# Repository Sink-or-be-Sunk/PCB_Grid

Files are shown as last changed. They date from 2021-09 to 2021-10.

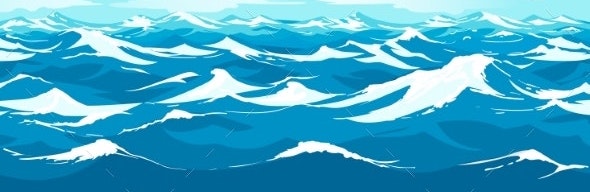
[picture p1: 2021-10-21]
assets/preview.jpeg

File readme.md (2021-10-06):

# Sink or be Sunk Grid PCB (Subcomponent)

This project contains the KiCAD PCB for one row of the attack of ship position boards
## Helpful Notes

### Nested Sheets

In KiCAD you can use a neat feature to split your project into multiple files. This not only helps to reduce cluter on one single diagram, it also allows for reuse of a common schematic element.

For this project specifically, the Grid.sch file can be reused for both the top (attack) grid and the bottom (ship positioning) grid.

`Hierarchical Labels` - KiCAD allows you to place a label on a nested sheet that can be viewed by the parenet sheet. Ex: you place a label on the STM32 Sheet and you can connect to it from the Main Layout schematic.

- Locate the `Hierarchical Labels` button on the right hand toolbar in kicad to place a label in a child sheet.
  - See section A4 of the STM32 Sheet
- Navigate back to the parent sheet and right click on the child sheet where you jused added the label
- Select the `import sheet pins` option
  - NOTE that you will have to do this for every new pin that you add to the child sheet, kinda repetative if you have a bunch of heirarchical labels...

`ESP32 Reference Design` - Adafruit produced a reference/dev board for the ESP32. They have great documentation on the device and are generous enough to include images of their schematic. This is a good place to start for our design. See the [Adafruit Website](https://learn.adafruit.com/adafruit-huzzah32-esp32-feather/downloads) for details.

#### Gride/Row PCB Updates

Started making some progress on our PCB layout. I'm already a little worried about space constraints. For a little more reference on the sizing: the width of the board is 22cm (2.5cm of extra clearance + 8in(20.32cm) = 22.82cm, rounded to 22cm to be on the safe side) and the length/height of the board is 2cm (0.787in). I was thinking to align one edge of each PCB with the edge of the grid - moreover, keep the 2.5cm extra all to one side for the resistor array, mux, connectors, etc.

The resistor array is pretty large, and I think we may have some issues trying to fit it on the board without running into a grid square. The same goes for the mux and the connectors we have chosen. On the brightside, if we make the board 2cm tall then that gives roughly 0.5cm of spacing between the boards. That's a good chunk of room. I'm trying to account for the wire connections, but could we thread the wires underneath the board? It will be on standoffs anyway.

Some things to consider:
- Is the resistor array worth it? Individual resistors = more solder time, resistor array = space constraints 
- Realistically, do we need a gap between rows? If so, how much? 

Looking forward, I think this PCB will be much simpler to layout, but will take a LOT of focus and attention to detail. The spacing is the most important part of this board. We will need to double, triple check this before purchasing.

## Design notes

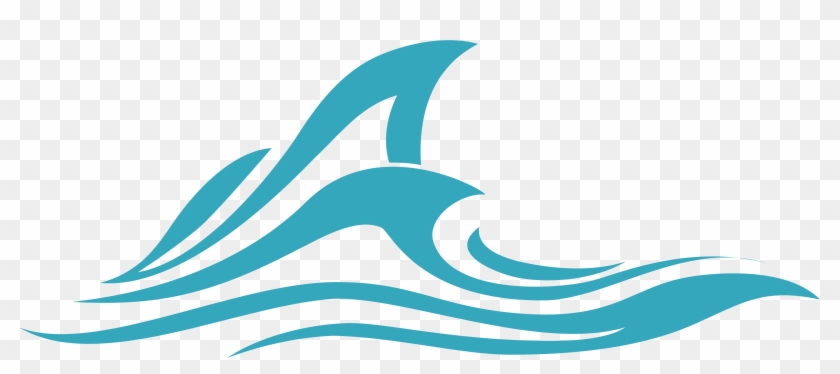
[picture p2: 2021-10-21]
assets/one_wave.png

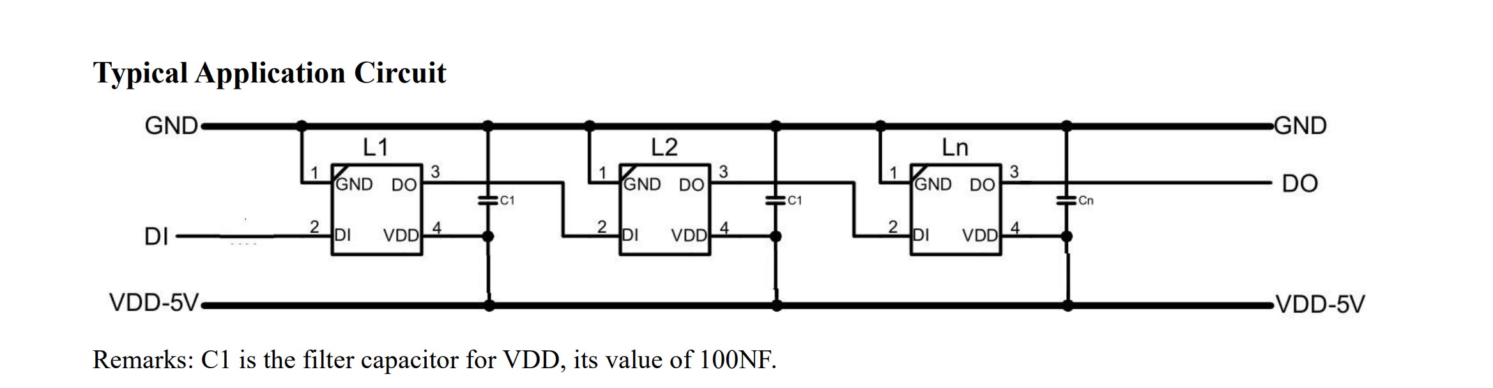
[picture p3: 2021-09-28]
docs/LED Typcial Circuit.jpg

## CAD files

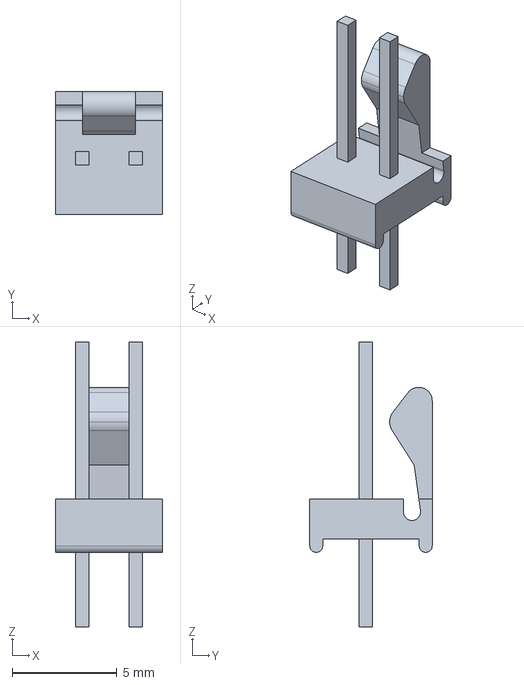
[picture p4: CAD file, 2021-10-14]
models/640456-2.step
5.08 x 5.84 x 13.6 mm

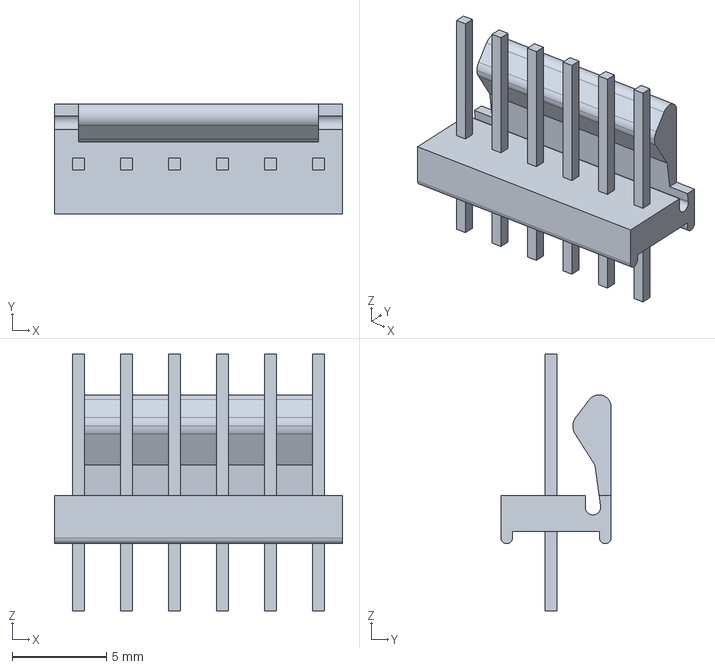
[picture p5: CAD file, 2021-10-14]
models/640456-6.step
15.2 x 5.84 x 13.6 mm

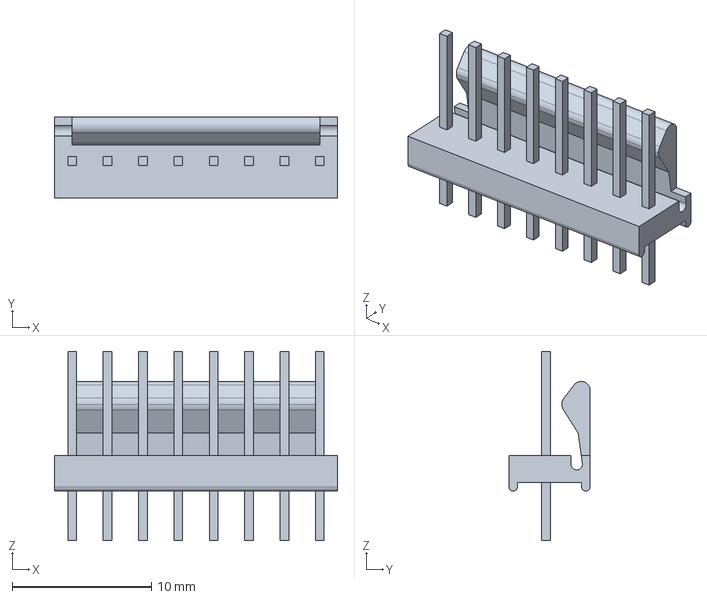
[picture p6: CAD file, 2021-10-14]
models/640456-8.step
20.3 x 5.84 x 13.6 mm

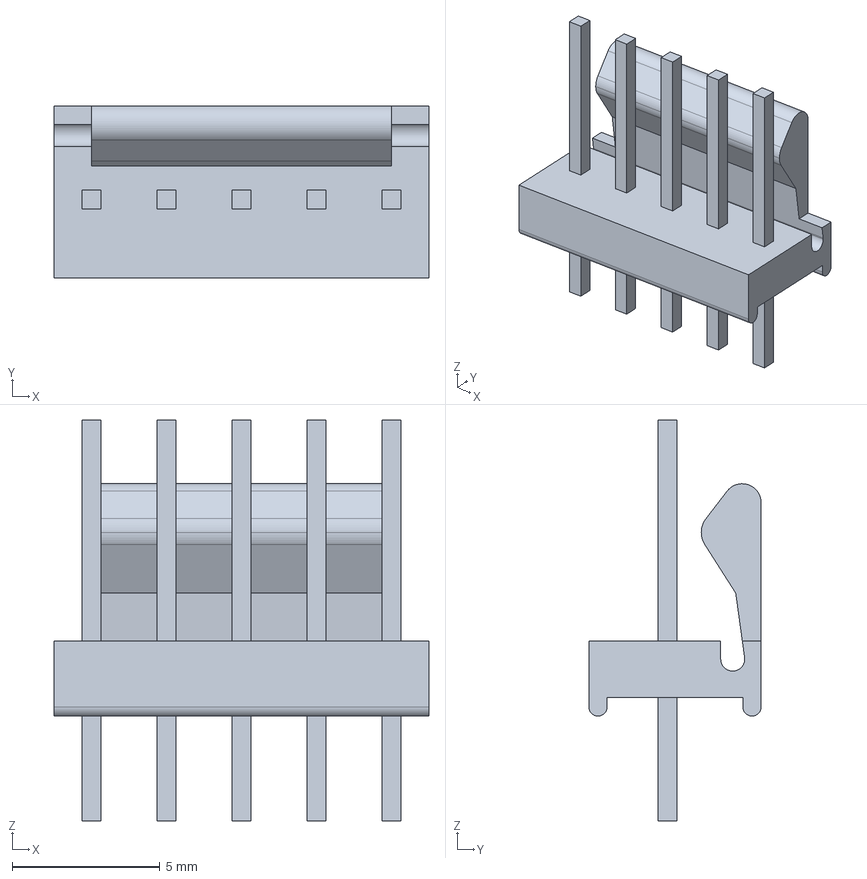
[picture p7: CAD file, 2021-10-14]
models/640456-5.step
12.7 x 5.84 x 13.6 mm

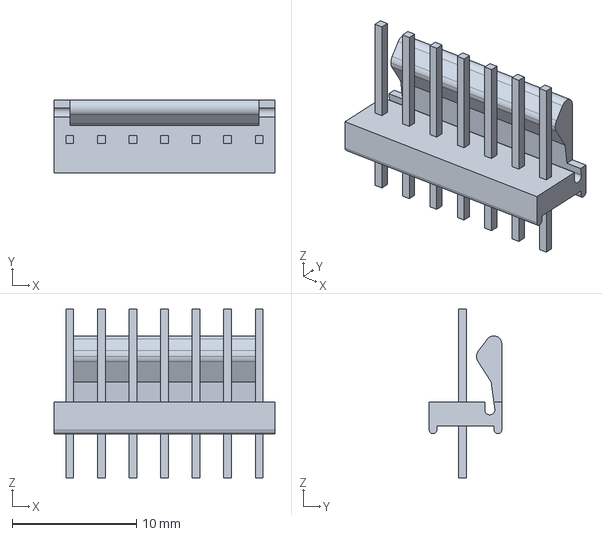
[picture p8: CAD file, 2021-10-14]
models/640456-7.step
17.8 x 5.84 x 13.6 mm

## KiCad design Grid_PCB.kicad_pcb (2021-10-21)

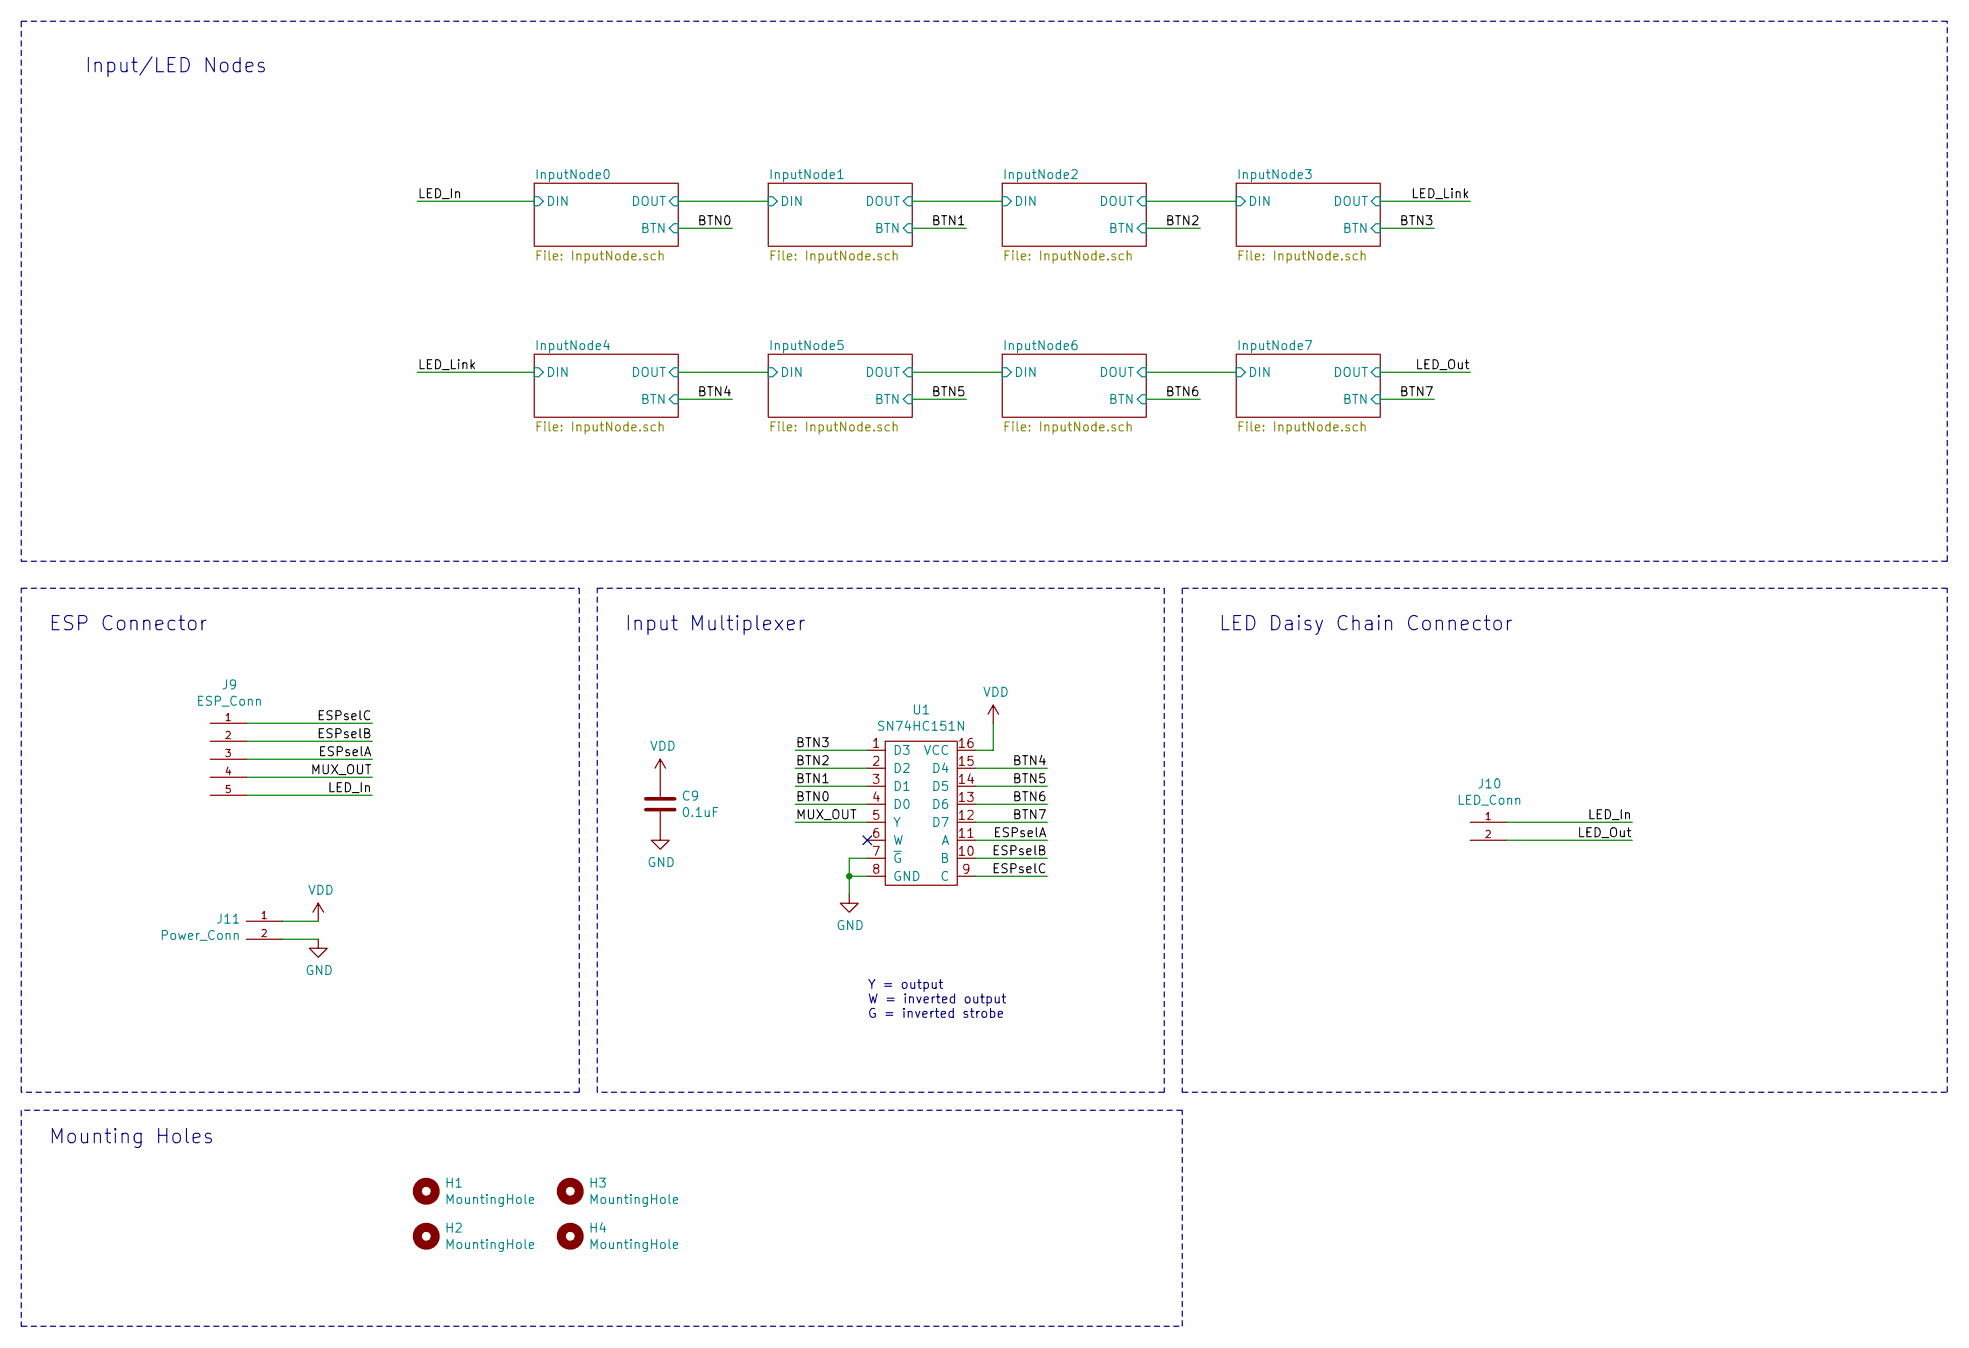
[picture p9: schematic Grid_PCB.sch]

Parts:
C9: 0.1uF; C_0805_2012Metric_Pad1.18x1.45mm_HandSolder
H1, H2, H3, H4: MountingHole; MountingHole_3.2mm_M3
J9: ESP_Conn; TE_640456-5
J10: LED_Conn; TE_640456-2
J11: Power_Conn; TE_640456-2
U1: SN74HC151N; DIP-16_W10.16mm

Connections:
/BTN1: U1.3 (D1); also elsewhere on the board
/BTN2: U1.2 (D2); also elsewhere on the board
/BTN3: U1.1 (D3); also elsewhere on the board
/BTN4: U1.15 (D4); also elsewhere on the board
/BTN6: U1.13 (D6); also elsewhere on the board
/BTN7: U1.12 (D7); also elsewhere on the board
/ESPselA: J9.3, U1.11 (A)
/ESPselB: J9.2, U1.10 (B)
/ESPselC: J9.1, U1.9 (C)
/LED_In: J9.5, J10.1; also elsewhere on the board
/LED_Out: J10.2; also elsewhere on the board
/MUX_OUT: J9.4, U1.5 (Y)
GND: C9.2, J11.2, U1.7 (~G), U1.8 (GND); also elsewhere on the board
VDD: C9.1, J11.1, U1.16 (VCC); also elsewhere on the board

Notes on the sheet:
Y = output W = inverted output G = inverted strobe
Input/LED Nodes
ESP Connector
Input Multiplexer
LED Daisy Chain Connector
Mounting Holes

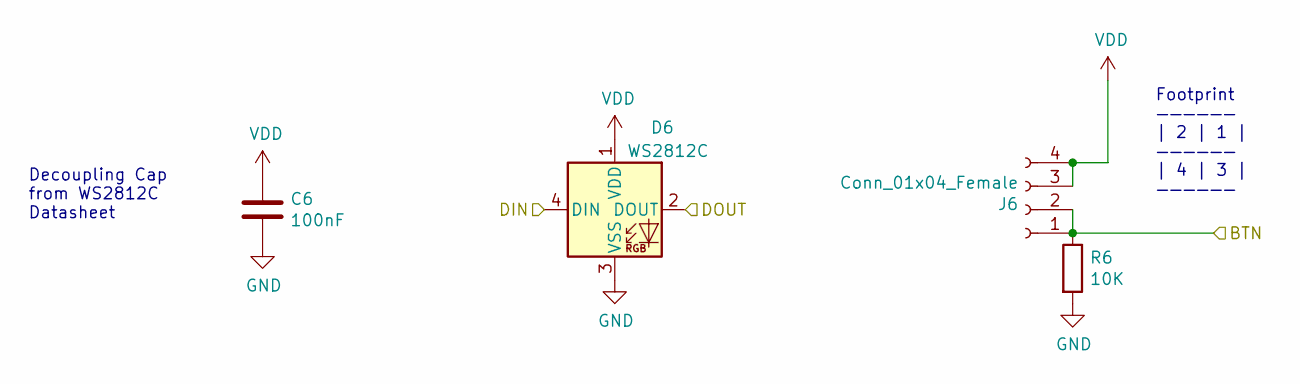
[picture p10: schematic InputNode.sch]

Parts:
C1: 100nF; C_0805_2012Metric_Pad1.15x1.40mm_HandSolder
D1: WS2812C; LED_WS2812B_PLCC4_5.0x5.0mm_P3.2mm
J6: Conn_01x04_Female; PinSocket_2x02_P2.54mm_Vertical
R1: 10K; R_0805_2012Metric_Pad1.20x1.40mm_HandSolder

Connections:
/InputNode1/DIN: D1.2 (DOUT); also elsewhere on the board
/LED_In: D1.4 (DIN); also elsewhere on the board
GND: C1.2, D1.3 (VSS), R1.2; also elsewhere on the board
VDD: C1.1, D1.1 (VDD), J6.3, J6.4; also elsewhere on the board

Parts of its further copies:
C2, C3, C4, C5, C6, C7, C8: 100nF; C_0805_2012Metric_Pad1.15x1.40mm_HandSolder
D2, D3, D4, D5, D6, D7, D8: WS2812C; LED_WS2812B_PLCC4_5.0x5.0mm_P3.2mm
J1, J2, J3, J4, J5, J7, J8: Conn_01x04_Female; PinSocket_2x02_P2.54mm_Vertical
R2, R3, R4, R5, R6, R7, R8: 10K; R_0805_2012Metric_Pad1.20x1.40mm_HandSolder

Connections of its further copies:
/BTN1: J2.1, J2.2, R2.1; also elsewhere on the board
/BTN2: J3.1, J3.2, R3.1; also elsewhere on the board
/BTN3: J4.1, J4.2, R4.1; also elsewhere on the board
/BTN4: J5.1, J5.2, R5.1; also elsewhere on the board
/BTN6: J7.1, J7.2, R7.1; also elsewhere on the board
/BTN7: J8.1, J8.2, R8.1; also elsewhere on the board
/InputNode1/DIN: D2.4 (DIN); also elsewhere on the board
/InputNode2/DIN: D2.2 (DOUT), D3.4 (DIN)
/InputNode3/DIN: D3.2 (DOUT), D4.4 (DIN)
/InputNode5/DIN: D5.2 (DOUT), D6.4 (DIN)
/InputNode6/DIN: D6.2 (DOUT), D7.4 (DIN)
/InputNode7/DIN: D7.2 (DOUT), D8.4 (DIN)
/LED_Link: D4.2 (DOUT), D5.4 (DIN)
/LED_Out: D8.2 (DOUT); also elsewhere on the board
GND: C2.2, C3.2, C4.2, C5.2, C6.2, C7.2, C8.2, D2.3 (VSS), D3.3 (VSS), D4.3 (VSS), D5.3 (VSS), D6.3 (VSS), D7.3 (VSS), D8.3 (VSS), R2.2, R3.2, R4.2, R5.2, R6.2, R7.2, R8.2; also elsewhere on the board
VDD: C2.1, C3.1, C4.1, C5.1, C6.1, C7.1, C8.1, D2.1 (VDD), D3.1 (VDD), D4.1 (VDD), D5.1 (VDD), D6.1 (VDD), D7.1 (VDD), D8.1 (VDD), J1.3, J1.4, J2.3, J2.4, J3.3, J3.4, J4.3, J4.4, J5.3, J5.4, J7.3, J7.4, J8.3, J8.4; also elsewhere on the board

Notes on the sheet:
Decoupling Cap from WS2812C Datasheet
Footprint —————— | 2 | 1 | —————— | 4 | 3 | ——————

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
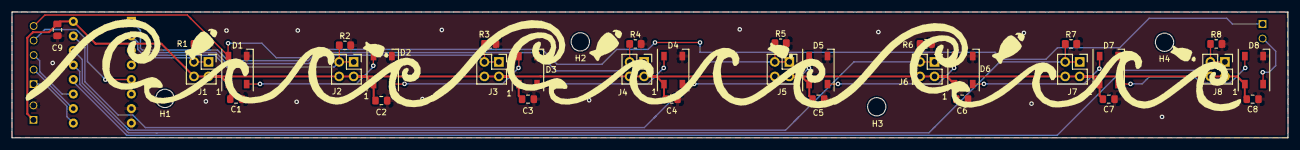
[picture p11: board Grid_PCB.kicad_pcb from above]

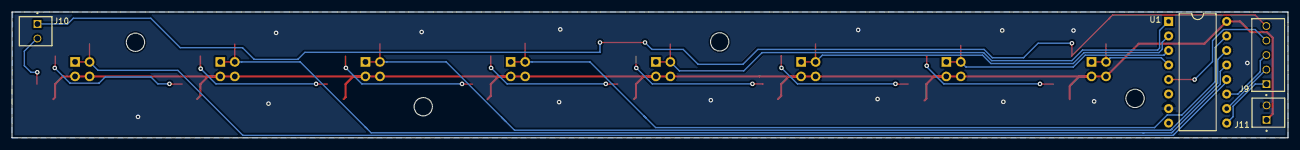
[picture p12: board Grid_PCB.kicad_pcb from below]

Board: 2 copper layers, 223.2 x 22.0 mm, 41 parts (4 on the bottom side), 23 nets.

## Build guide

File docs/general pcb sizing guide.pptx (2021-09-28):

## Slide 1

O | O | O | O | O | O | O | O
O | O | O | O | O | O | O | O
O | O | O | O | O | O | O | O
O | O | O | O | O | O | O | O
O | O | O | O | O | O | O | O
O | O | O | O | O | O | O | O
O | O | O | O | O | O | O | O
O | O | O | O | O | O | O | O

Handle Hole

0.75 in

13 in

LCD Display
(80mm by 36 mm)

3.15 in

8 in

1.5 in

1 in

1 in

RUMBLE MOTOR
(24 mm)

SPEAKER
(40 mm)

11 in

KEYPAD
(MAIN PCB BELOW)

2.6 in

3 in

8 in

Battery
(0.7in x 0.7in x 2.7in)

3.5 in

3.5 in

2 in

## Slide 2

Handle Hole

O | O | O | O | O | O | O | O
O | O | O | O | O | O | O | O
O | O | O | O | O | O | O | O
O | O | O | O | O | O | O | O
O | O | O | O | O | O | O | O
O | O | O | O | O | O | O | O
O | O | O | O | O | O | O | O
O | O | O | O | O | O | O | O

13 in

2 in

0.75 in

3.5 in

This space to be used for boat storage

3.5 in

0.75 in

8 in

11 in

8 in

3.3 in

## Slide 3

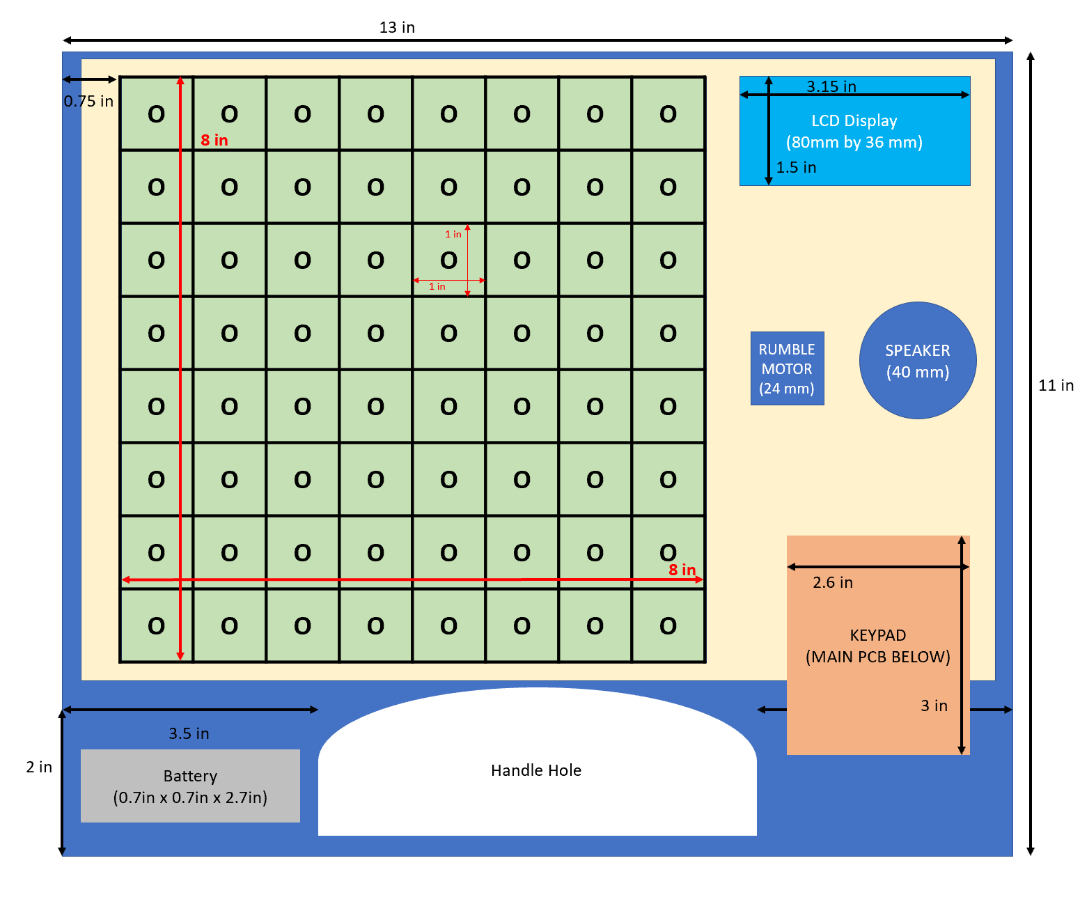
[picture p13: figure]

Row PCBs

Main PCB

ESP32

Battery
(0.7in x 0.7in x 2.7in)

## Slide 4

0.6 in

9 in

0.8 in

0.6 in

0.4 in

Boat Detection Lines

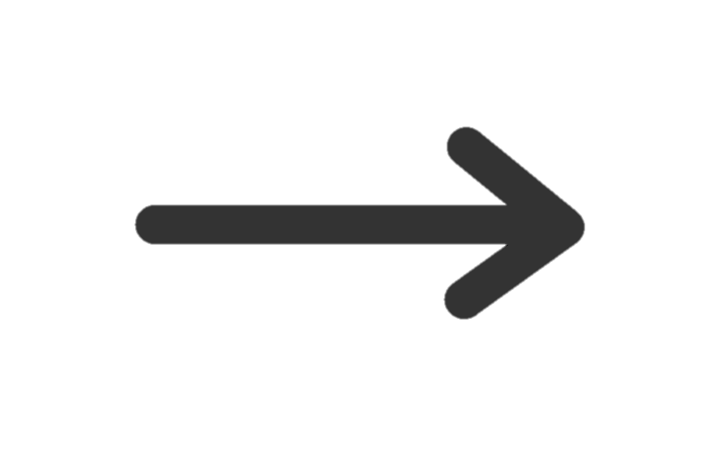
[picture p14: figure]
ARROW png images | PNGWing

ESP32

Battery charging

3 in

Additional components

Keypad input

3 in

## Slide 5

(0.5 in, 0.5 in)

O | O

(1.5 in, 0.5 in)

(0 in, 0 in)

Number of Boat Pegs | Total Size (l, w) | Boat Peg Coordinates*
2 | 2in x 1in | (0.5in, 0.5in) (0.5in, 1.5in)
3 | 3in x 1 in | (0.5in, 0.5in) (0.5in, 1.5in) (0.5in, 2.5in)
4 | 4in x 1 in | (0.5in, 0.5in) (0.5in, 1.5in) (0.5in, 2.5in) (0.5in, 3.5in)
5 | 5in x 1 in | (0.5in, 0.5in) (0.5in, 1.5in) (0.5in, 2.5in) (0.5in, 3.5in) (0.5in, 4.5in)

O | O | O

O | O | O | O

O | O | O | O | O

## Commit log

2021-09-28 First Draft of Row/Grid PCB
    [row.kicad_pcb, row.sch]
2021-09-28 transered nested project into root and moved docs into docs/ folder
    [Grid_PCB.sch, InputNode.sch, row.kicad_pcb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]
2021-10-01 updated for homepage
    [Grid_PCB.sch, InputNode.sch]
2021-10-04 added resistor network and updated mnt hole footprint
    [Grid_PCB.sch, InputNode.sch]
2021-10-06 PCB layout updates
    [Grid_PCB.kicad_pcb, InputNode.sch]
2021-10-06 continued progress
    [Grid_PCB.kicad_pcb]
2021-10-06 finished first pass at routing
    [Grid_PCB.kicad_pcb, Grid_PCB.sch, InputNode.sch]
2021-10-07 updated with todo for routing around screws
    [Grid_PCB.sch, InputNode.sch]
2021-10-09 trace update
    [Grid_PCB.kicad_pcb]
2021-10-11 flipped components to back side
    [Grid_PCB.kicad_pcb, Grid_PCB.sch]
2021-10-12 rotated the mux
    [Grid_PCB.kicad_pcb]
2021-10-12 minor silkscreen and mounting hole fix
    [Grid_PCB.kicad_pcb]
2021-10-12 fixed added cap for mux and fixed drc errors
    [Grid_PCB.kicad_pcb, Grid_PCB.sch, InputNode.sch]
2021-10-13 finsihed sch and pcb
    [Grid_PCB.kicad_pcb]
2021-10-13 minor fix to mux strobe (enable) pin
    [Grid_PCB.kicad_pcb, Grid_PCB.sch]
2021-10-14 updated conns and mounting holes
    [Grid_PCB.kicad_pcb, Grid_PCB.sch, InputNode.sch]
2021-10-14 updated conns, moved mounting holes
    [640456-2.step, 640456-5.step, 640456-6.step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]
2021-10-19 updated jst footprint/library and updated routing on sel signals
    [640456-2.step, 640456-5.step, 640456-6.step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]
2021-10-19 updated hole footprint
    [Grid_PCB.kicad_pcb, Grid_PCB.sch, InputNode.sch]
2021-10-20 first attempt at waves
    [Grid_PCB.kicad_pcb]
2021-10-21 wave pattern attempt
    [Grid_PCB.kicad_pcb]
2021-10-21 wave 2
    [Grid_PCB.kicad_pcb]
2021-10-21 wave 2 light
    [Grid_PCB.kicad_pcb]
2021-10-21 wave 3
    [Grid_PCB.kicad_pcb]
2021-10-21 wave 4
    [Grid_PCB.kicad_pcb]
2021-10-21 wave 4 skinny
    [Grid_PCB.kicad_pcb]
2021-10-21 wave fish
    [Grid_PCB.kicad_pcb]
2021-10-21 wave fish middle
    [Grid_PCB.kicad_pcb]
2021-10-21 pruned footprint library
    [Grid_PCB.kicad_pcb]
